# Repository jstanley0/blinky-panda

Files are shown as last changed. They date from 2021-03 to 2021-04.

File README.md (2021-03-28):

# blinky-panda
an electronic art project, basically

panda-pride

I made this for the design challenge, to learn KiCad better, to test out fabrication of a non-rectangular board, and for soldering practice.

There are 25 LEDs logically arranged in a 5x5 matrix, and a simple timer-driven program that drives them with independent 6-bit software PWM.

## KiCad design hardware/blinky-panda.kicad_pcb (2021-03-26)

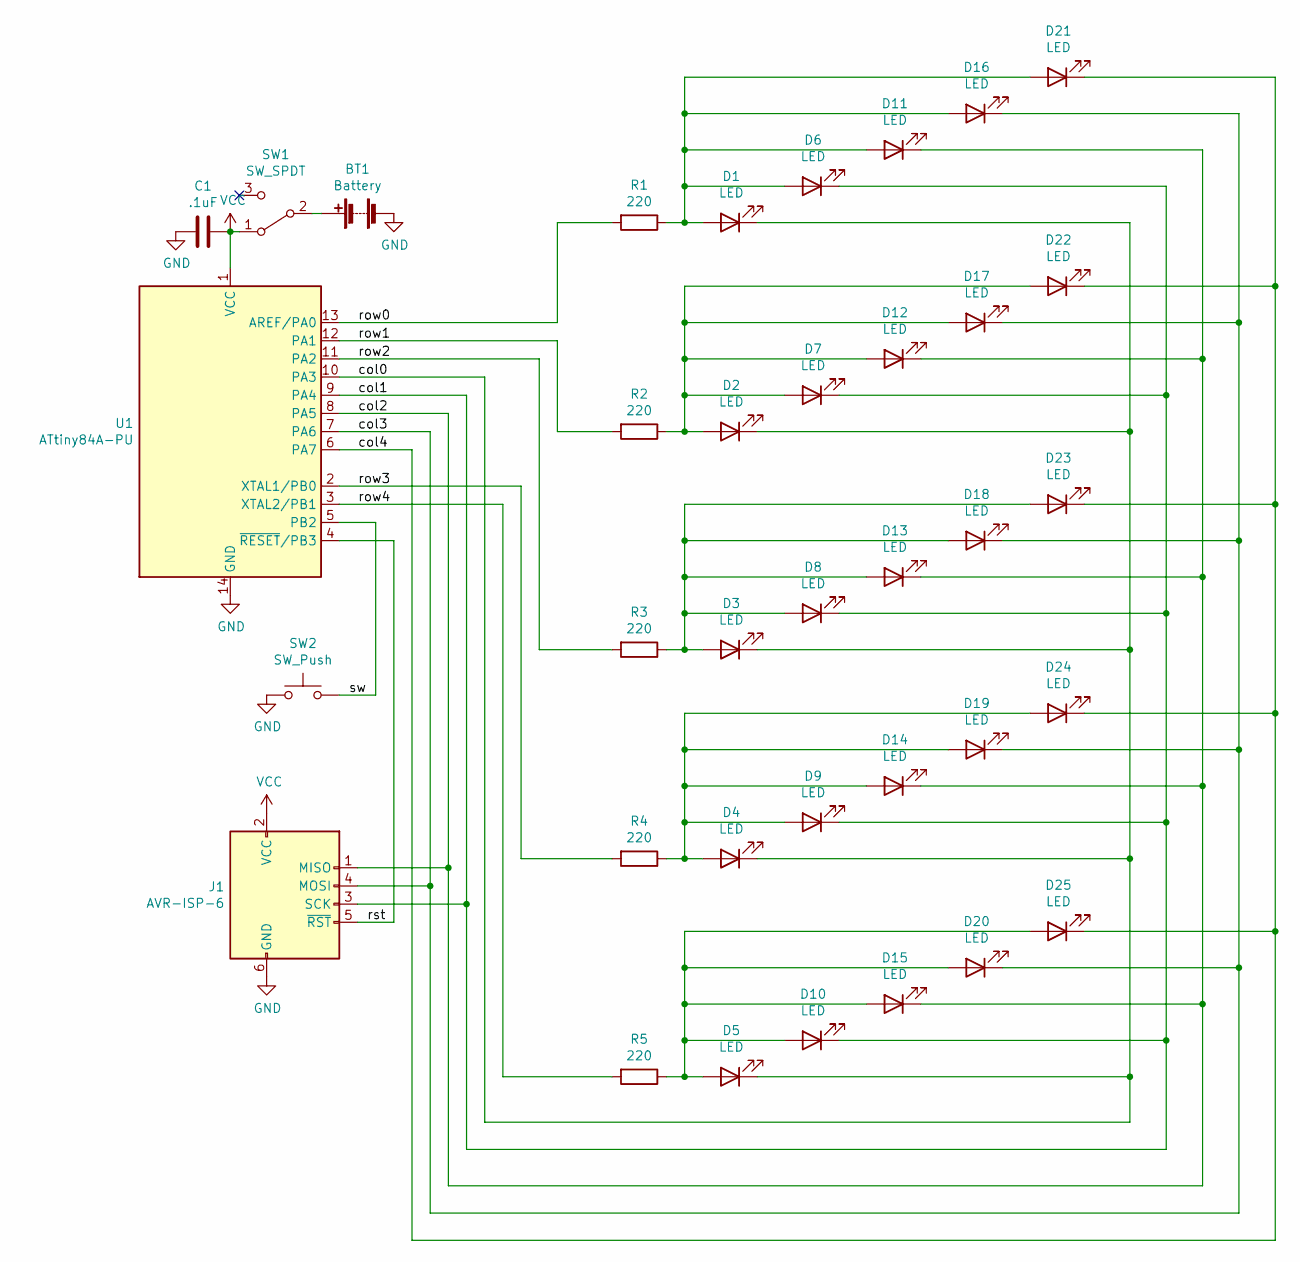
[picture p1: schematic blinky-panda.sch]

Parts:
BT1: Battery; PinHeader_1x02_P2.54mm_Vertical
C1: .1uF; C_Disc_D3.0mm_W1.6mm_P2.50mm
D1, D2, D3, D4, D5, D6, D7, D8, D9, D10, D11, D12, D13, D14, D15, D16, D17, D18, D19, D20, D21, D22, D23, D24, D25: LED; LED_D5.0mm_Clear
J1: AVR-ISP-6; PinHeader_2x03_P2.54mm_Vertical
R1, R2, R3, R4, R5: 220; R_Axial_DIN0204_L3.6mm_D1.6mm_P7.62mm_Horizontal
SW1: SW_SPDT; Switch_Slide_11.6x4mm_EG1218
SW2: SW_Push; SW_Tactile_Straight_KSL0Axx1LFTR
U1: ATtiny84A-PU; DIP-14_W7.62mm

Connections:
/col0: D1.1 (K), D2.1 (K), D3.1 (K), D4.1 (K), D5.1 (K), U1.10 (PA3)
/col1: D6.1 (K), D7.1 (K), D8.1 (K), D9.1 (K), D10.1 (K), J1.3 (SCK), U1.9 (PA4)
/col2: D11.1 (K), D12.1 (K), D13.1 (K), D14.1 (K), D15.1 (K), J1.1 (MISO), U1.8 (PA5)
/col3: D16.1 (K), D17.1 (K), D18.1 (K), D19.1 (K), D20.1 (K), J1.4 (MOSI), U1.7 (PA6)
/col4: D21.1 (K), D22.1 (K), D23.1 (K), D24.1 (K), D25.1 (K), U1.6 (PA7)
/row0: R1.2, U1.13 (AREF/PA0)
/row1: R2.2, U1.12 (PA1)
/row2: R3.2, U1.11 (PA2)
/row3: R4.2, U1.2 (XTAL1/PB0)
/row4: R5.2, U1.3 (XTAL2/PB1)
/rst: J1.5 (~RST), U1.4 (~RESET~/PB3)
/sw: SW2.2, U1.5 (PB2)
GND: BT1.2 (-), C1.2, J1.6 (GND), SW2.1, U1.14 (GND)
unnamed: BT1.1 (+), SW1.2 (B)
unnamed: D1.2 (A), D6.2 (A), D11.2 (A), D16.2 (A), D21.2 (A), R1.1
unnamed: D5.2 (A), D10.2 (A), D15.2 (A), D20.2 (A), D25.2 (A), R5.1
unnamed: D2.2 (A), D7.2 (A), D12.2 (A), D17.2 (A), D22.2 (A), R2.1
unnamed: D3.2 (A), D8.2 (A), D13.2 (A), D18.2 (A), D23.2 (A), R3.1
unnamed: D4.2 (A), D9.2 (A), D14.2 (A), D19.2 (A), D24.2 (A), R4.1
VCC: C1.1, J1.2 (VCC), SW1.1 (A), U1.1 (VCC)

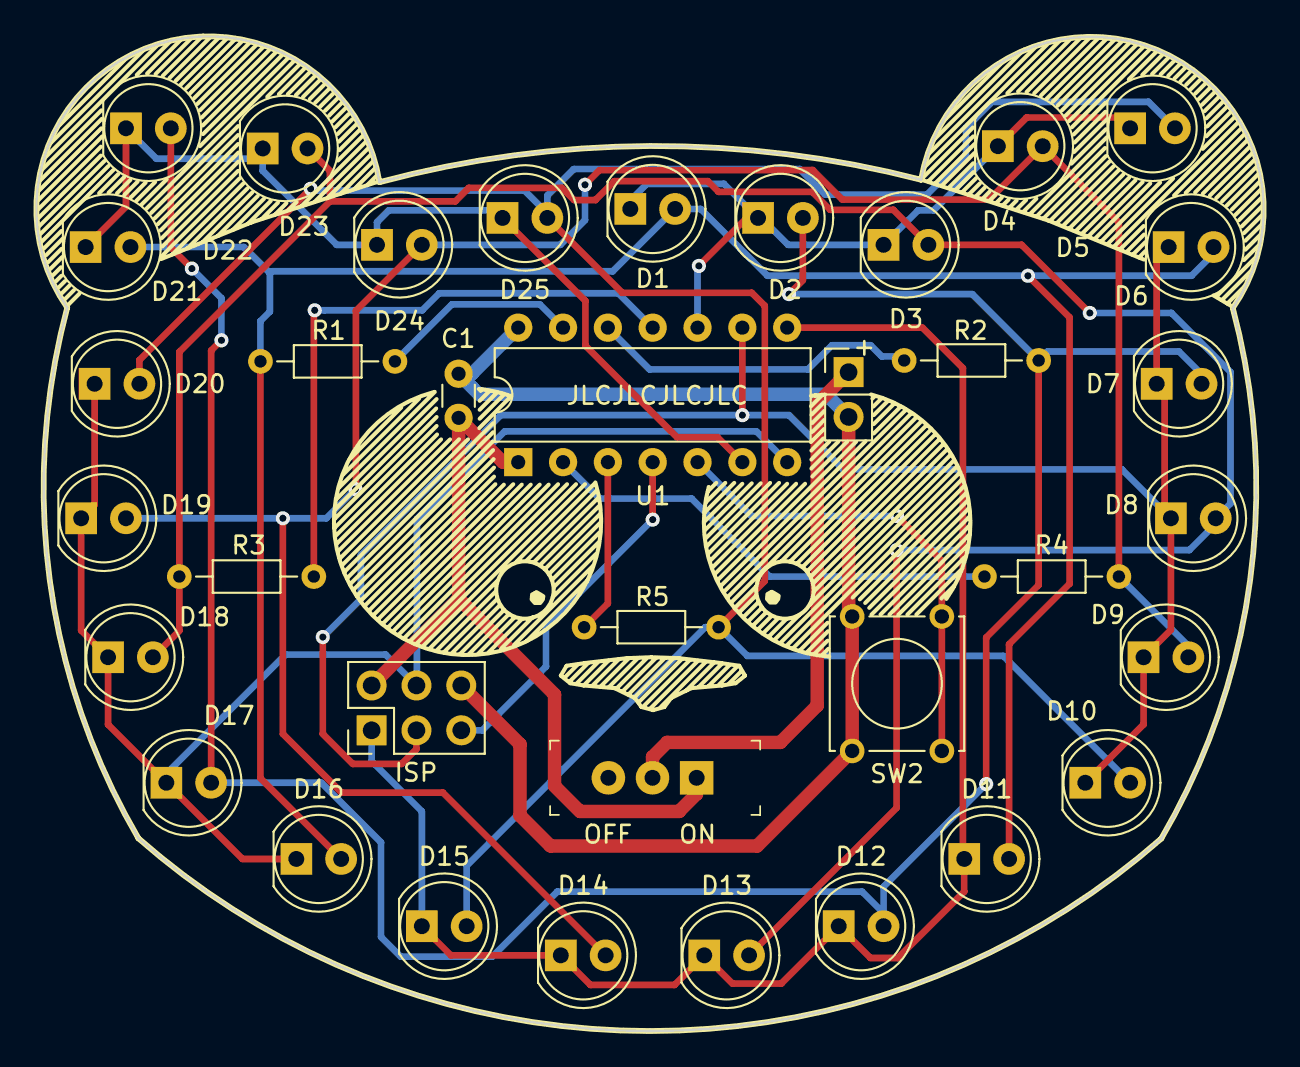
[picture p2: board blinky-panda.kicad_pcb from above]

Board: 2 copper layers, 69.5 x 56.4 mm, 36 parts (0 on the bottom side), 20 nets.

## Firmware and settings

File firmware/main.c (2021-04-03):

// blinky-panda
// (c) 2021 by Jeremy Stanley

// port assignments:
// PA0..PA2 -> row0..row2 anodes
// PA3..PA7 -> col0..col4 cathodes
// PB0..PB1 -> row3..row4 anodes
// PB2      -> tactile switch

// amount of time to spend on a single pattern, in milliseconds
// (note this is an unsigned 16-bit value)
#define PATTERN_MS 10000

#include <avr/io.h>
#include <avr/pgmspace.h>
#include <avr/sleep.h>
#include <avr/interrupt.h>
#include <util/delay.h>
#include <stdlib.h>

#define COL_ON(col) PORTA = 0b11111000 ^ (0b1000 << col); PORTB &= 0b11111100

// for software-PWM performance reasons this is all unrolled
// also this avoids conditionals over which port to address
#define ROW_0_ON() PORTA |= 1
#define ROW_0_OFF() PORTA &= ~1
#define ROW_1_ON() PORTA |= 0b10
#define ROW_1_OFF() PORTA &= ~0b10
#define ROW_2_ON() PORTA |= 0b100
#define ROW_2_OFF() PORTA &= ~0b100
#define ROW_3_ON() PORTB |= 1
#define ROW_3_OFF() PORTB &= ~1
#define ROW_4_ON() PORTB |= 0b10
#define ROW_4_OFF() PORTB &= ~0b10

#define BUTTON_STATE() (PINB & (1 << PB2))

void init_io()
{
  DDRA  = 0b11111111;
  PORTA = 0b11111000;
  DDRB  = 0b00000011;
  PORTB = 0b00000100;
}

void init_timer()
{
    TCCR0B = (1 << CS00);
    TIMSK0 = (1 << TOIE0);
}

volatile uint8_t framebuf[25] = {0};

ISR(TIM0_OVF_vect)
{
    static uint8_t count = 0;
    static uint8_t col = 0, base = 0;

    if (count == 0) {
        // switch column and clear rows
        if (++col == 5) {
            col = 0;
            base = 0;
        } else {
            base += 5;
        }
        COL_ON(col);

        // enable rows that are on
        if (framebuf[base]) ROW_0_ON();
        if (framebuf[base+1]) ROW_1_ON();
        if (framebuf[base+2]) ROW_2_ON();
        if (framebuf[base+3]) ROW_3_ON();
        if (framebuf[base+4]) ROW_4_ON();

    } else {
        // turn off rows
        if (count >= framebuf[base]) ROW_0_OFF();
        if (count >= framebuf[base+1]) ROW_1_OFF();
        if (count >= framebuf[base+2]) ROW_2_OFF();
        if (count >= framebuf[base+3]) ROW_3_OFF();
        if (count >= framebuf[base+4]) ROW_4_OFF();
    }

    count = (count + 1) & 0x3F;
}

void fade_out()
{
    for(uint8_t i = 0; i < 6; ++i) {
        for(uint8_t j = 0; j < 25; ++j) {
            framebuf[j] >>= 1;
        }
        _delay_ms(10);
    }
}

int update()
{
    static uint16_t pattern_ms = 0;

    uint8_t pre = BUTTON_STATE();
    _delay_ms(25);  // <- must be a compile-time constant
    pattern_ms += 25;

    // switch to the next pattern if the time limit on this one has been exceeded or the button has been pressed
    if ((pattern_ms >= PATTERN_MS) || (BUTTON_STATE() && !pre)) {
        pattern_ms = 0;
        fade_out();
        return 1;
    }

    return 0;
}

int fade()
{
    if (update())
        return 1;

    for(uint8_t z = 0; z < 25; ++z) {
        framebuf[z] >>= 1;
    }
    return 0;
}

void chase3()
{
  int8_t i = 0, j = rand() % 25, k = 13;
  for(;;) {
    framebuf[i] = 63;
    framebuf[j] = 127;
    framebuf[k] = 63;
    if (fade())
        break;
    if (++i >= 25)
      i = 0;
    if (i & 1) {
      if (--j < 0)
        j = 24;
    }
    if (++k >= 25)
      k = 0;
  }
}

void raindrops()
{
  for(;;) {
    for(int8_t i = 0; i < 3; ++i) {
        framebuf[rand() % 25] = 255;
    }
    if (fade())
        break;
  }
}

void shimmer()
{
    uint8_t i = 0;
    for(;;) {
        for(int8_t j = i; j < 25; j += 5) {
            framebuf[j] = 255;
        }
        if (fade())
            return;
        if (++i == 5)
            i = 0;
    }
}

void cycle()
{
    uint8_t i = 0, j = 0;
    for(;;) {
        for(int8_t j = i; j < 25; j += 5) {
            framebuf[j] = 63;
        }
        if (fade())
            return;
        if (++j == 2) {
            j = 0;
            if (++i == 5)
                i = 0;
        }
    }
}

void sparkle()
{
    for(;;)
    {
        for(int8_t i = 1; i < 64; i <<= 1) {
            for(int8_t j = 0; j < 25; ++j) {
                framebuf[j] = i;
            }
            if (update())
                return;
        }

        for(int8_t i = 63; i >= 0; --i) {
            for(int8_t j = 0; j < 25; ++j) {
                framebuf[j] = i;
            }
            framebuf[rand() % 25] = 63;
            if (fade())
                return;
        }

        for(int8_t i = 0; i < 10; ++i) {
            framebuf[rand() % 25] = 63;
                if (fade())
                    return;
        }
    }
}

int main(void)
{
  init_io();
  init_timer();

  sei();

  for(;;) {
    chase3();
    shimmer();
    raindrops();
    cycle();
    sparkle();
  }

}

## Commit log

2021-02-26 kind of a mess
    [blinky-panda.kicad_pcb, blinky-panda.sch]
2021-02-26 complete circuit
    [blinky-panda.kicad_pcb]
2021-02-28 darker shading
    [blinky-panda.kicad_pcb]
2021-02-28 rework pin assignments to fix isp
    I thought maybe it'd be a bad idea to have SCK connected to MOSI
    through a 220 ohm resistor.
    in this arrangement, power won't flow from one programming pin
    to another (they'll all hit reverse diodes)
    [blinky-panda.kicad_pcb, blinky-panda.sch]
2021-03-27 four-and-a-half-bit glitchy PWM
2021-03-27 Revert "a different approach"
    that was supposed to go in a branch but I fail at git
    This reverts commit 89ce5d6298b26ac84308afc0da870f66a3a9225a.
    [main.c]
2021-03-27 six-bit not-obviously-glitchy PWM
    with 97Hz effective refresh rate!
    [main.c]
